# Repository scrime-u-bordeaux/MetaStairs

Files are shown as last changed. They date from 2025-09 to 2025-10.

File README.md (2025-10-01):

# MetaStairs (Metapiano + Pianostairs)

A project designed for the *Nuit des Escaliers 2025* event, organized by the *Opéra de Bordeaux* in the framework of the *Journées du Patrimoine 2025* and presented to the public at the *Pôle Juridique et Judidiaire* of the University of Bordeaux.

This repository contains :
* [The MIDI controller's firmware](./Arduino) that we wrote to turn stairs into a giant MIDI controller keyboard.
* [A python program](./Python) reacting to incoming MIDI messages from the controller according to different operating modes.
* A Reaper project receiving the MIDI messages processed by the python script and playing the notes with various VST plugins according to the current operating mode.

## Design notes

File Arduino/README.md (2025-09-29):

# MIDI Stairs Controller

### A simple 9 pressure sensitive keys controller to be installed on 9 stair steps

The `MIDIStairsController` Arduino sketch is designed to be uploaded to a Teensy 4.1 board.  
It takes 9 analog inputs from FSR ribbon sensors, smoothes them a little and detects press and release events on each FSR.  
It uses a two-threshold + velocity based algorithm that is able to detect the pressing velocity reliably.  
On press event detection it sends a MIDI `NOTE ON` message with the corresponding velocity.  
On release event detection it sends a MIDI `NOTE OFF` message.  
Each sensor is bound to a specific MIDI note (1 for input A1, 2 for input A2, etc).  
The 9 FSR sensors should be wired to analog inputs A1 to A9 (pins 15 to 23, see [teensy 4.1 official page](https://www.pjrc.com/store/teensy41.html)), following this schema :  

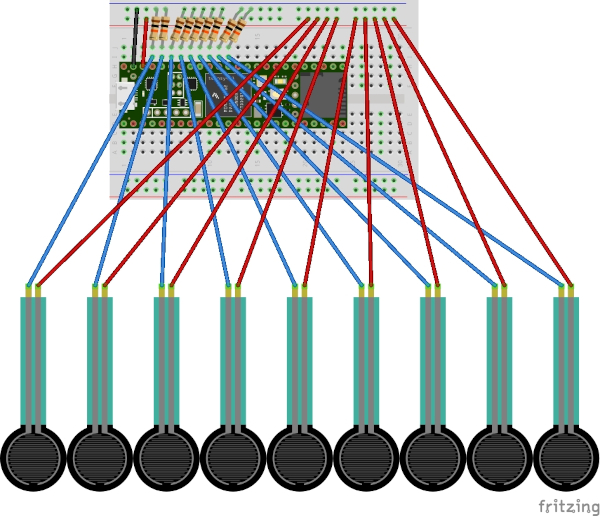
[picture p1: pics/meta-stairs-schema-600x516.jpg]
wiring diagram


We made this prototype board for the event :  

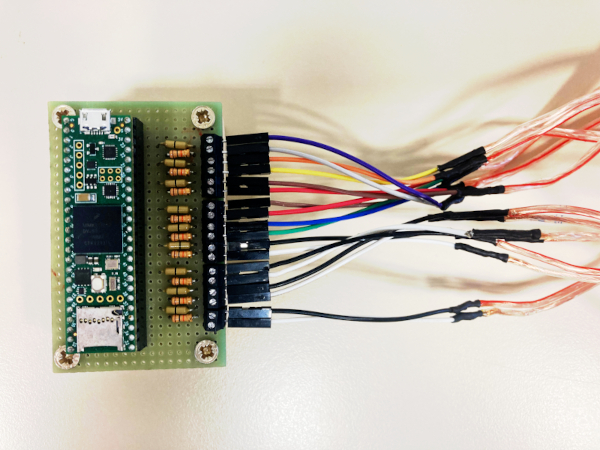
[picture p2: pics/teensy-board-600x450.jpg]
prototyping board


We soldered jumper wire ends to both extremities of 2 meters long copper speaker cables to connect the FSR sensors to the board's screw terminals.  
We used [these FSR sensors](https://www.lextronic.fr/capteur-de-force-fsr4-1202.html) on which we mounted [these adapters](https://www.lextronic.fr/connecteur-femelle-2-plots-pour-fsr-31549.html) for ease of use, robustness and transportability :

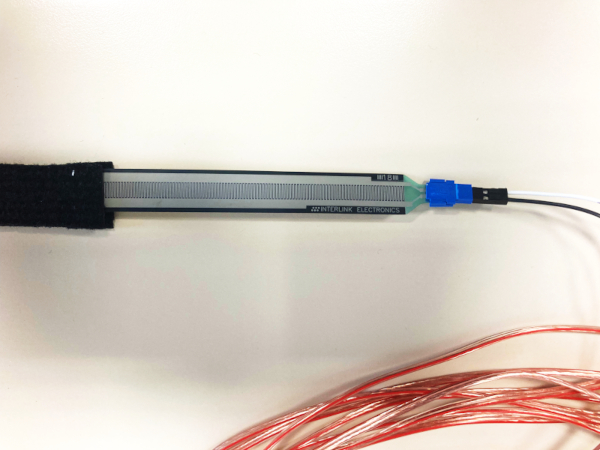
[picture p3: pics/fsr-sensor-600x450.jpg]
fsr sensors


We cut black carpet pieces and painted white stripes on them to visualize the sensors that we installed underneath.  
Once setup, the interactive stairs looked like this :  

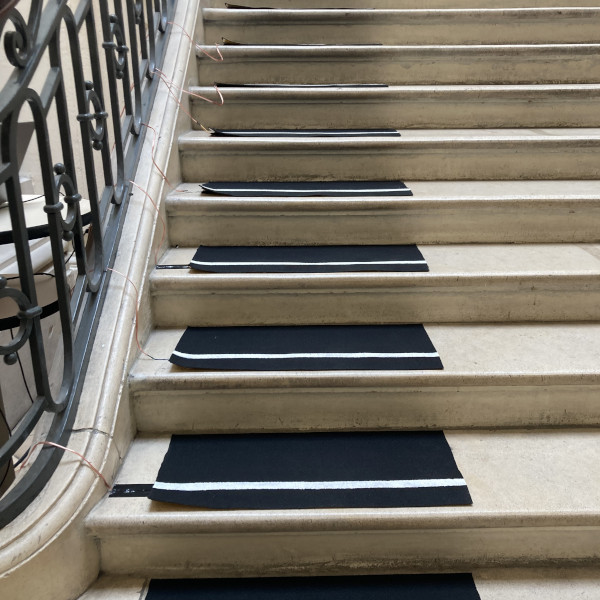
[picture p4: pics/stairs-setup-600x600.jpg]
stairs setup


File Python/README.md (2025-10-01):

# MetaStairs engine

A multi-mode MIDI note events processor for the MetaStairs project

## installation

NB : you might need to replace `python` with `python3` in the below commands as this is a python 3 program.

* `cd` into this folder
* create `venv` : `python -m venv .venv`
* activate `venv` : `source .venv/bin/activate` on mac
* install requirements : `python -m pip install -r requirements.txt`
* start script : `python meta_stairs.py`

## usage

When the script starts, it will prompt you to select various MIDI inputs and outputs.  
On Mac, we used several IAC busses (you can create more than the default one from the native *Audio and MIDI configuration* app).  

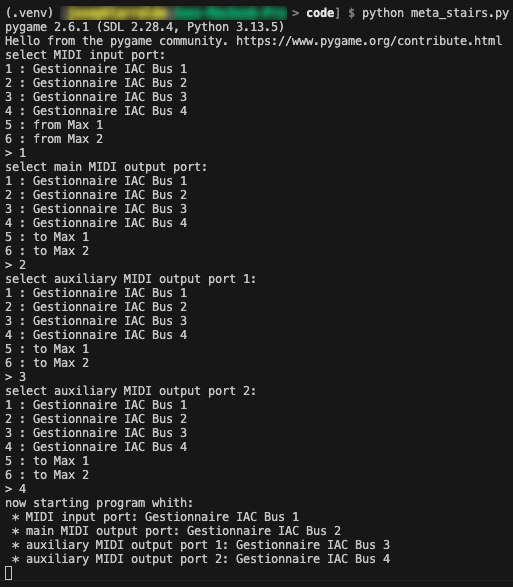
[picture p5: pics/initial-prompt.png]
initial prompt


* If the `MIDI Stairs Controller` is connected via USB, you should select it as the `MIDI input port`, or you can select another device for testing like a regular MIDI keyboard controller.  
* For the `main MIDI output port`, select e.g IAC Bus 2 on Mac (we used this bus as input port in Reaper, but you could use e.g Jack on Linux or rtpMIDI on Windows instead). The `main MIDI output port` is used by the internal modes (all modes except `midifile performer` and `meta impro`).  
Read on for more information on modes.  
* The selected `auxiliary MIDI output ports 1 and 2` should be different from the `main MIDI output port` and used as MIDI input ports by the `midifile performer` and `meta impro` external processes, respectively. These processes should then send their MIDI messages to the same port as the selected `main MIDI output port` (or whatever other port Reaper is listening to) so that they can be played by the Reaper project.  

Once the MIDI inputs and outputs have been selected, a window opens and allows to switch between different modes :

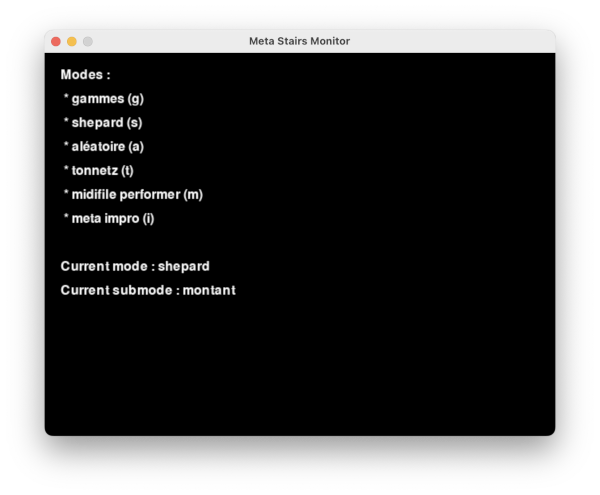
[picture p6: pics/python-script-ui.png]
pygame ui


Each mode can be selected by a letter shortcut and one can navigate through its submodes using the arrow keys :

* gammes (g) : with this mode each step has a fixed note assigned, it's similar to a regular keyboard but submodes define various scales :
    * diatonique (all steps are white piano keys)
    * chromatique (consecutive steps are spaced by a semitone)
    * gamme par ton (consecutive steps are spaced by a full tone)
* shepard (s) : each step is a shepard note and depending on the submode :
    * montant : on each new step, the next shepard note is the next upper semitone
    * descendant : on each new step, the next shepard note is the next lower semitone
* aléatoire (a) : no submode, on each new step a random note from the 88 key piano ambitus is played (this one is trivial and we didn't really use it)
* tonnetz (t) : no submode, every NOTE ON events a new scale is generated from a triad obtained via random tonnetz navigation and spread across all the piano octaves. Each step randomly plays a note from a subset of all possible notes, depending on its position (lower steps play lower notes and higher step play heigher notes). With 9 steps, each step usually has a choice of 2 notes, whatever triad is active.
* midifile performer (m) : this mode is delegated to an external process, see below
* meta impro (i) : this mode is also delegated to an external process, see below

Modes are responsible for defining the MIDI channels on which they sends their messages (they are actually all hardcoded in `modes/orchestrator.py`), which will target specific virtual instruments in the Reaper project. For instance, all modes will send messages on channel 1 by default and will be played by a virtual piano, except modes shepard (channel 2, played by a marimba), tonnetz (channel 3, played by a celesta), and the meta impro program (channel 4, played by a rhodes-like electric piano).

The `midifile performer` mode is operated by a web app that can be accessed [here](https://scrime-apps.labri.fr/web-midifile-performer-dev). It should be run on Chrome for MIDI support. You can also [clone](https://github.com/scrime-u-bordeaux/web-midifile-performer) it and use the `develop` branch locally. For the moment the app is not able to remap the original MIDI channels from the loaded files to user defined ones, but we used piano scores encoded with messages on channel 1 (in our case, this targeted the virtual piano in Reaper so it was ok).

The `meta impro` mode is operated by an experimental variant of the `midifile performer` web app that provides several improvisation modes. It is a python program that should be executed locally. A specific branch (`nuit-des-escaliers`) was created for this project and the code is available [here](https://github.com/scrime-u-bordeaux/metaImpro). The MIDI output channel is hardcoded so you have to modify it from the source if you want to change it.

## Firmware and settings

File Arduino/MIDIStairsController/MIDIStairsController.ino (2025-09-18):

#define NB_OF_KEYS 9
#define MIDI_OUT_CHANNEL 1
// #define DEBUG 1

#include "PressureToNoteEvents.h"

struct noteGenData {
  uint8_t analogInput;
  uint8_t note;
  float processed = 0.f;
};

noteGenData noteGeneratorsData[NB_OF_KEYS] = {
  // { A0, 0 },
  { A1, 1 },
  { A2, 2 },
  { A3, 3 },
  { A4, 4 },
  { A5, 5 },
  { A6, 6 },
  { A7, 7 },
  { A8, 8 },
  { A9, 9 }
};

class MidiNotesSender : public PressureToNoteEvents::Listener {
  virtual void onNoteEvent(uint8_t note, uint8_t velocity) {
    if (velocity > 0) {
      usbMIDI.sendNoteOn(note, velocity, MIDI_OUT_CHANNEL);
    } else {
      usbMIDI.sendNoteOff(note, 0, MIDI_OUT_CHANNEL);
    }
  }
};

MidiNotesSender midiNotesSender;
PressureToNoteEvents* noteGenerators[NB_OF_KEYS];
bool calibrating = true;
uint64_t startDate = millis();

void setup() {
#ifdef DEBUG
  Serial.begin(115200);
#endif

  for (auto i = 0; i < NB_OF_KEYS; ++i) {
    noteGenerators[i] = new PressureToNoteEvents(noteGeneratorsData[i].note);
    noteGenerators[i]->setCalibrating(true);
    noteGenerators[i]->setListener(&midiNotesSender);
  }

  digitalWrite(13, HIGH); // set the LED on

  startDate = millis();
}

void loop() {
  if (calibrating && startDate - millis() > 3000) {
    calibrating = false;
    for (auto gen : noteGenerators) {
      gen->setCalibrating(false);
      Serial.println(gen->minValue);
    }
    Serial.println("stop calibrating");
  }

  float value;
  for (auto i = 0; i < NB_OF_KEYS; ++i) {
    value = analogRead(noteGeneratorsData[i].analogInput) / 1024.f;
    noteGeneratorsData[i].processed = noteGenerators[i]->process(value);
  }
  
#ifdef DEBUG
  for (const auto& data : noteGeneratorsData) {
    Serial.print(data.processed);
    Serial.print(",");
  }
  Serial.println("0,1");
#endif

  while (usbMIDI.read()) {
    // manage modes here according to MIDI input,
    // e.g enter thresh calibration mode on some NOTE ON event
  }

  delay(1);
}

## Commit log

2025-07-23 Add files via upload
    ajout des fonctions nécessaires au fichier modeJeu.py
2025-07-24 Ajout du répertoire code avec les scripts .py
2025-09-02 add Arduino repository
2025-09-02 suppression des anciens fichiers finalShepard.py metastairsAccord.py metastairsAccordAvecVolume.py
2025-09-02 maj des codes midifileMetastairs.py shepard.py avec option denregistrement
2025-09-17 add auto-calibration for velocity detection
2025-09-18 firmware tested ok for nuit des escaliers
2025-09-29 documentation in progress
    [meta-stairs-schema.fzz]
